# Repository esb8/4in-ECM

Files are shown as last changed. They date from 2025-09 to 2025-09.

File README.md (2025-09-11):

# Media
Use Export KiCad Images Workflow

---

<div align="center">
  <div>
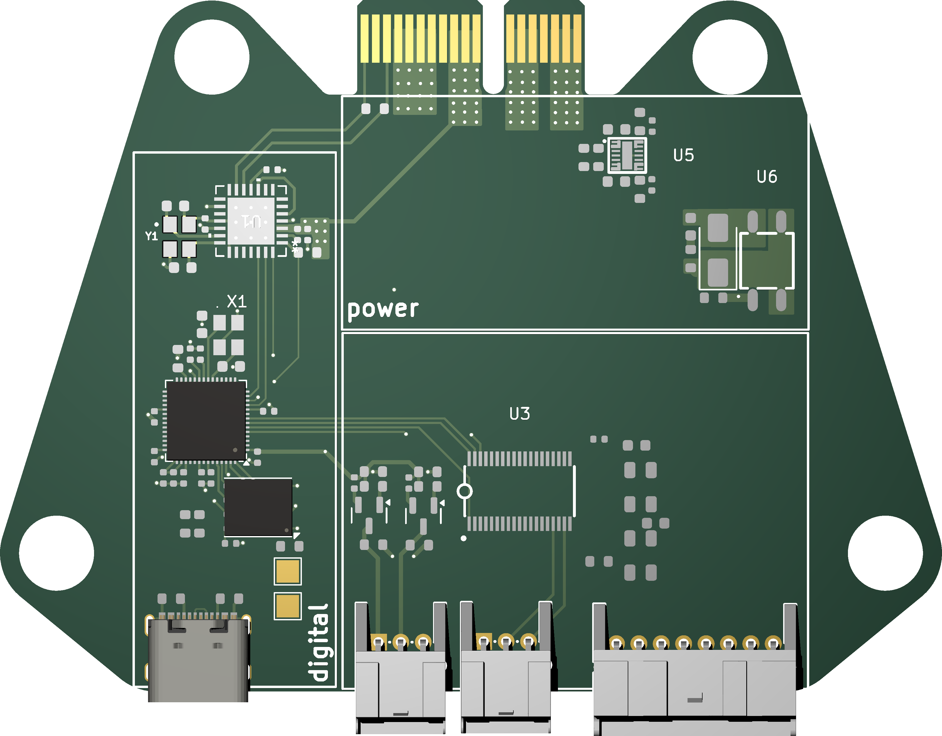
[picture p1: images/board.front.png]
    
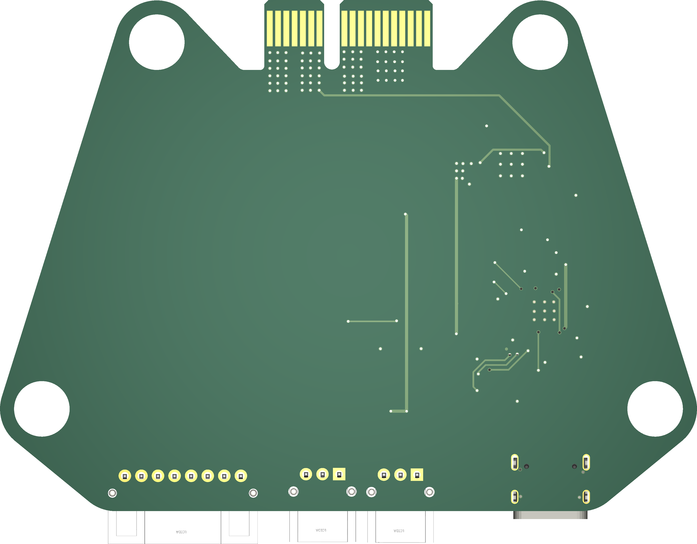
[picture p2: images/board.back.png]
    
    <p><em>3D Render</em></p>
  </div>
  <br>

  <div>
    Schematic<br>
    <p><em>Schematic</em></p>
  </div>
  <br>
  
  <div>
    Front
    Back<br>
    <em>Footprint</em>
  </div>
</div>

# Engine Control Module

## Overview  
The **Engine Control Module (ECM)** is a **control and data acquisition (DAQ) system** designed for liquid rocket engine testing. It integrates sensor measurement, actuation control, and data logging into a compact embedded system suitable for ground testing and development.  

The system is capable of:  
- Monitoring **up to 4 pressure transducers**  
- Reading multiple **thermocouples** for temperature measurement  
- Controlling **1 solenoid valve** (on/off flow control)  
- Driving **2 servo motors** (valve actuation or gimbal control)  
- Logging sensor data for analysis and verification  

---

## Features  
- **Data Acquisition**  
  - 4 analog channels for high-accuracy pressure transducers  
  - Integrated thermocouple interface for combustion chamber and feed line monitoring  
  - Real-time sampling and logging  

- **Actuation**  
  - Solenoid driver with high-side switching capability  
  - Dual servo motor outputs (PWM control)  
  - Configurable control logic for sequencing and automation  

- **System Control**  
  - Embedded microcontroller (e.g., STM32/Arduino/FPGA – specify)  
  - USB/UART interface for PC communication  
  - Safety interlocks and emergency shutdown support  

- **Software**  
  - Firmware for DAQ, control, and communications  
  - Logging utility for test data collection  
  - Configurable sampling rates and actuation sequences  

---

## Applications  
- Small-scale **liquid rocket engine testing**  
- **Valve and feed system automation**  
- **Sensor data acquisition** for propulsion research  
- **Ground support equipment** integration  

---

## Getting Started  
1. **Hardware Setup**  
   - Connect pressure transducers to the analog input ports (0–5 V or 0–10 V).  
   - Connect thermocouples to the thermocouple inputs.  
   - Wire solenoid to the high-side driver output.  
   - Connect servos to PWM headers.  

2. **Software Setup**  
   - Flash firmware using the provided source code.  
   - Install the DAQ/logging software on your PC.  
   - Configure serial port and sampling rate.  

3. **Operation**  
   - Power on the ECM.  
   - Verify sensor calibration.  
   - Execute control sequences via PC interface or onboard logic.  

---

## Safety Notes  
⚠️ This module is intended for **research and experimental use only**.  
- Always follow proper test stand safety procedures.  
- Use protective enclosures and remote operation where possible.  
- Ensure solenoid and servo actuation logic is validated before hot-fire testing.

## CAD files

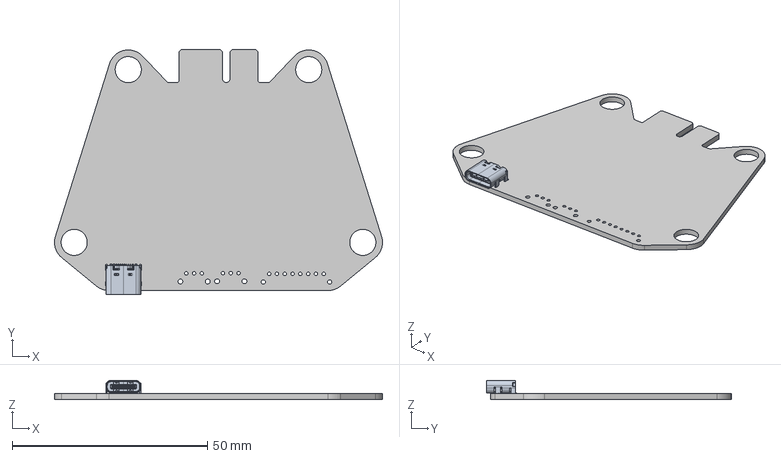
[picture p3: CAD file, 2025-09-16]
images/board.step
84.1 x 62.7 x 4.91 mm
USB_C_Receptacle_GCT_USB4105-xx-A_16P_TopMnt_Horizontal
ECM_PCB

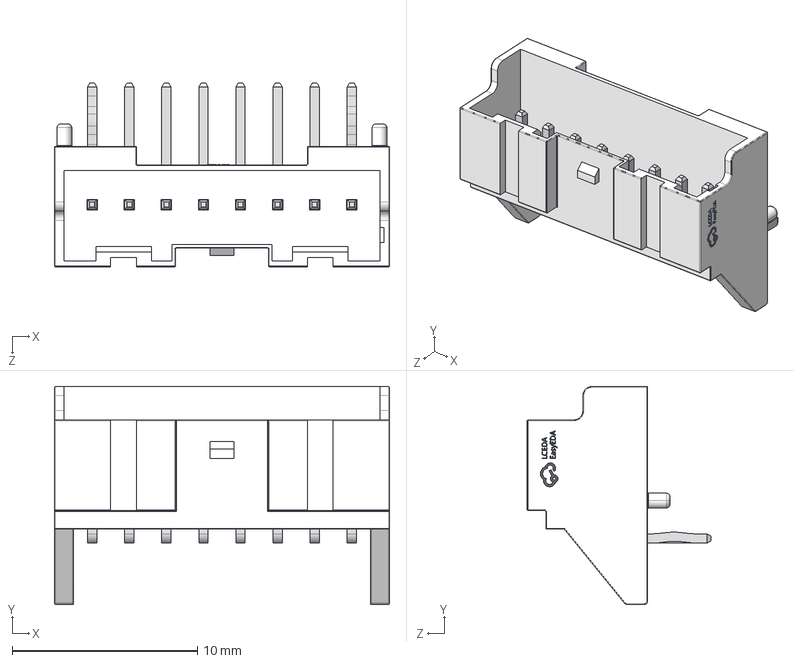
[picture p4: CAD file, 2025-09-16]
kicad/models/CONN-TH_S08B-PASK-2.step
18.1 x 11.8 x 9.90 mm

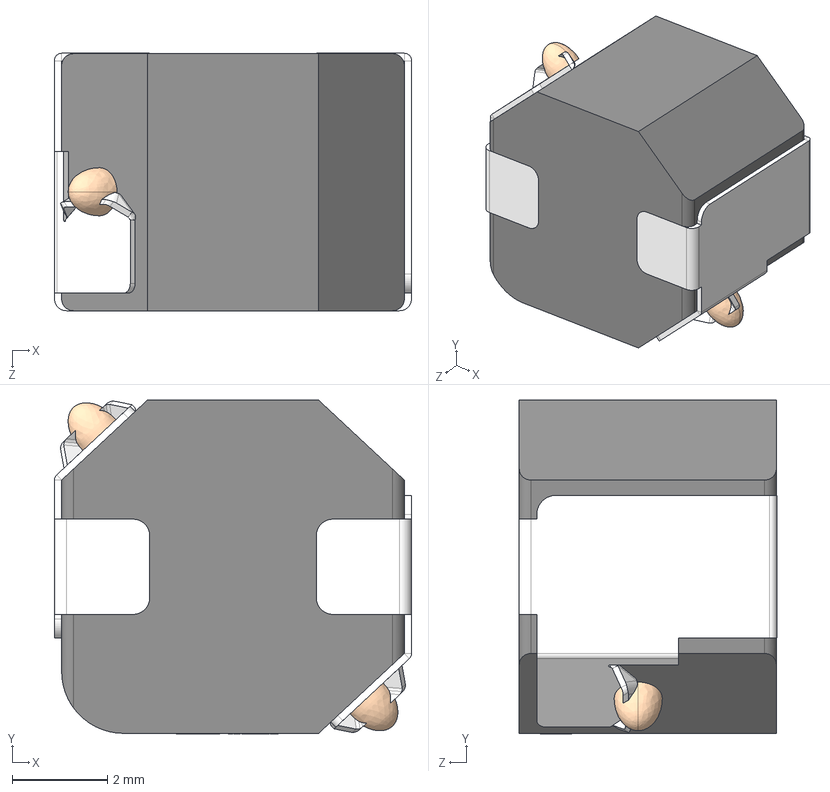
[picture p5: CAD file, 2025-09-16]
kicad/models/IND-SMD_L7.5-W7.0_SPM7054VT-330M-D.step
7.50 x 7.01 x 5.41 mm

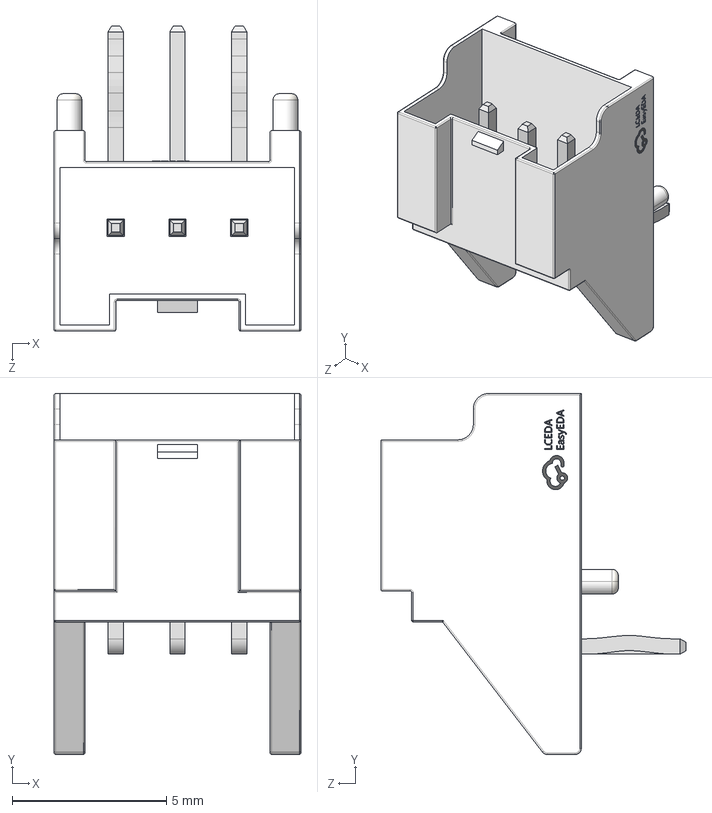
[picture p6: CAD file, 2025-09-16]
kicad/models/CONN-TH_S03B-PASK-2-LF-SN.step
8.00 x 11.7 x 9.90 mm

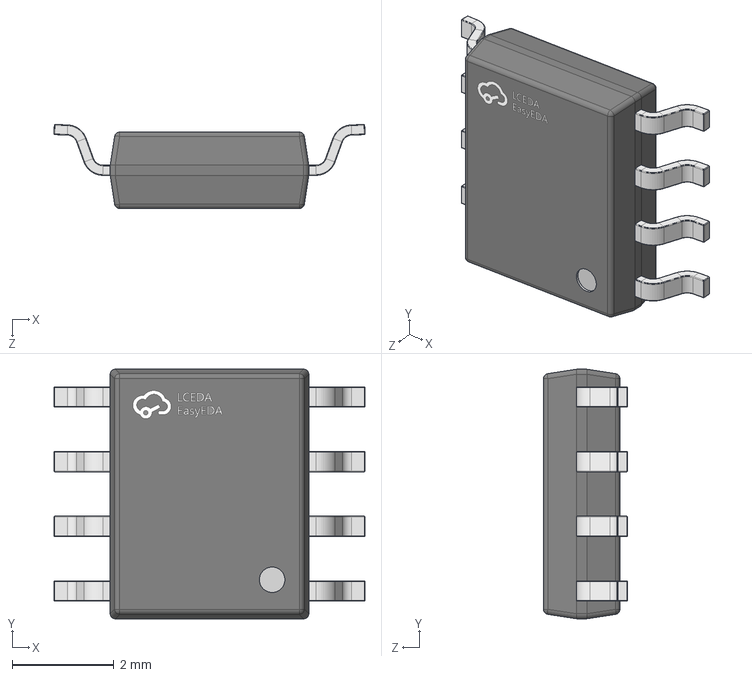
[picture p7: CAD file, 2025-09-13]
kicad/models/SO-8_L4.9-W3.9-H1.5-LS5.9-P1.27.step
6.11 x 4.90 x 1.65 mm

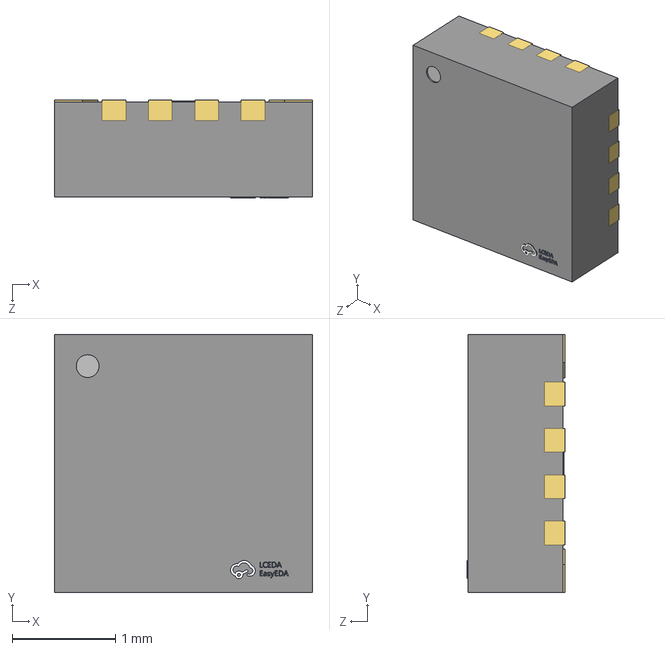
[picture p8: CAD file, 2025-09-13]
kicad/models/QFN-16_L2.5-W2.5-P0.45-TL-EP0.6.step
2.50 x 2.50 x 0.95 mm

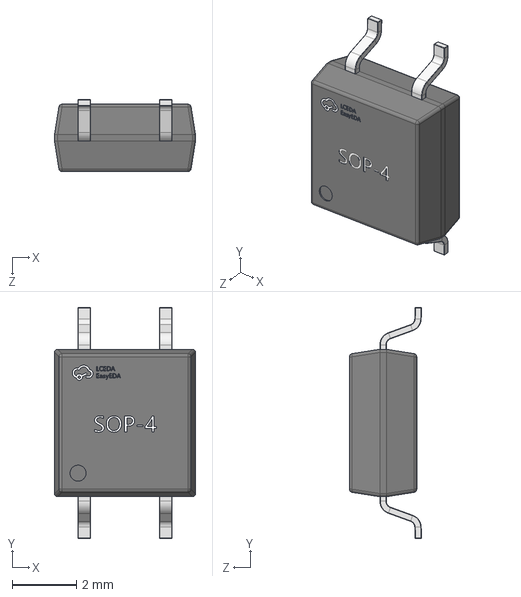
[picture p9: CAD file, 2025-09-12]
kicad/models/SOP-4_L4.4-W4.6-H2.1-LS7.0-P2.54.step
4.40 x 7.21 x 2.25 mm

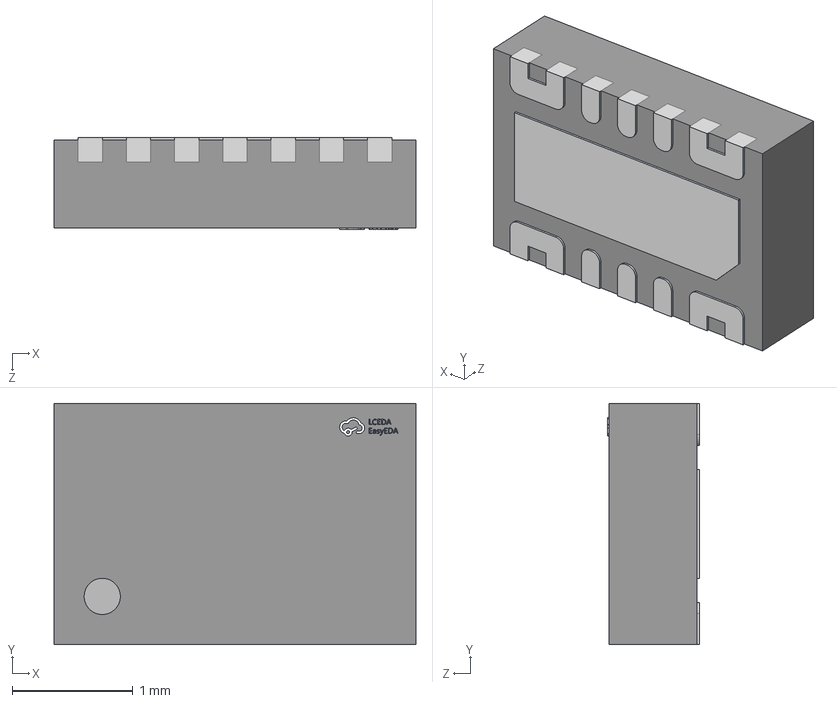
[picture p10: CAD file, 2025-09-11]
kicad/models/WSON-14_L3.0-W2.0-P0.40-BL-EP-1.step
3.00 x 2.00 x 0.76 mm

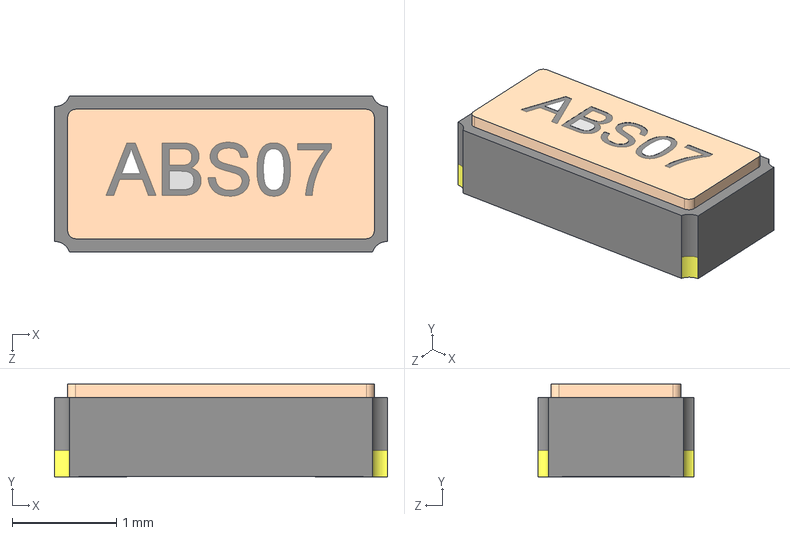
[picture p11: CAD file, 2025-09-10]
kicad/models/ABS07-32.768KHZ-T.step
3.20 x 0.889 x 1.50 mm

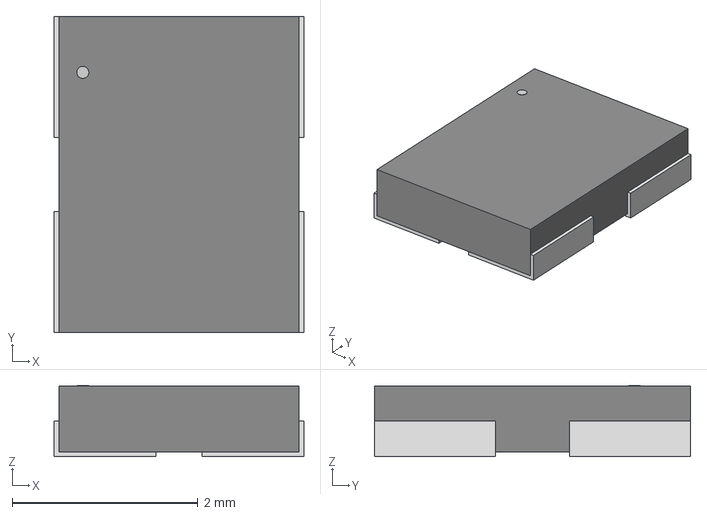
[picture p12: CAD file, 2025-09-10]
kicad/models/ABM8-272-T3_ABR.step
2.69 x 3.40 x 0.765 mm

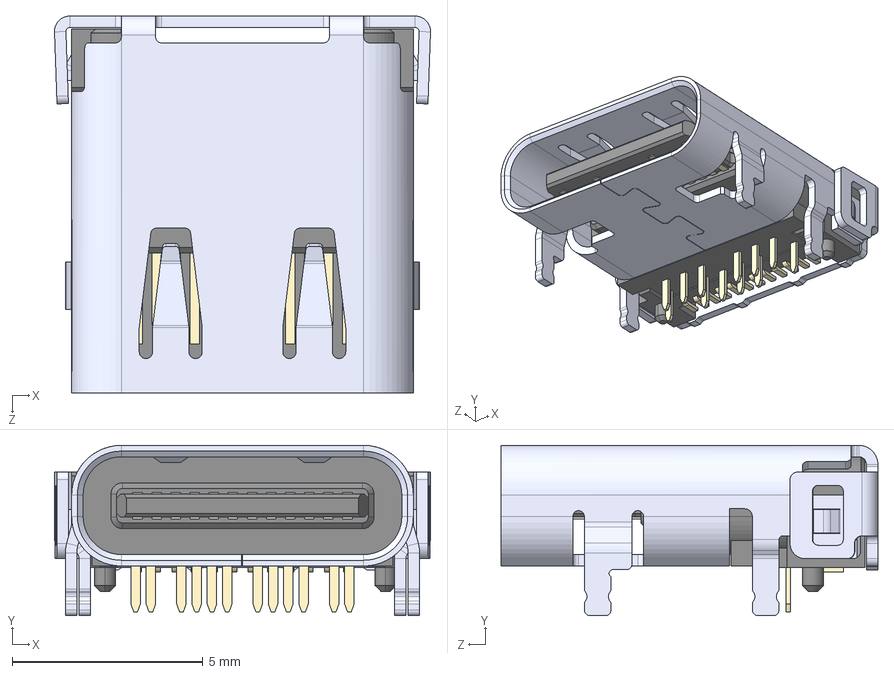
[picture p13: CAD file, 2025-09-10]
kicad/models/TYPE-C-31-M-04.step
9.85 x 4.46 x 9.87 mm

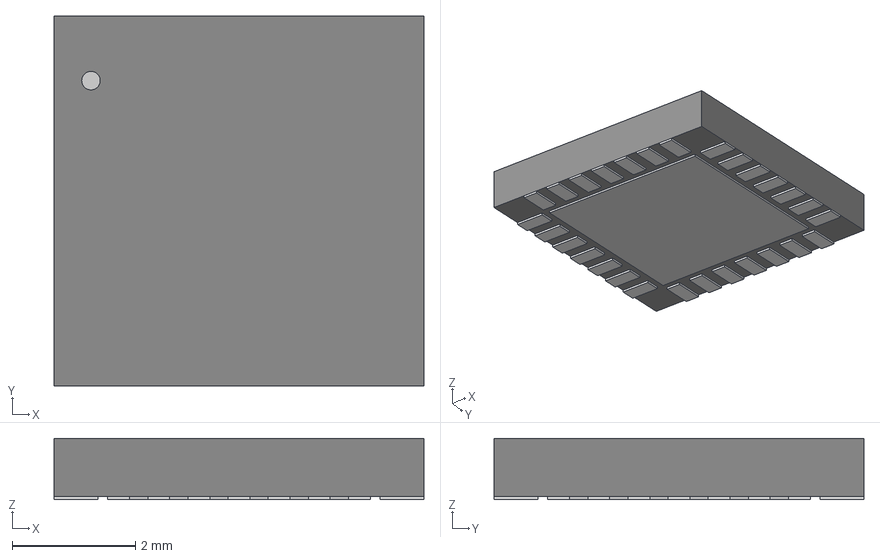
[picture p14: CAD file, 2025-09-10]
kicad/models/QFN28_6X6MC_MCH.step
5.99 x 5.99 x 0.993 mm

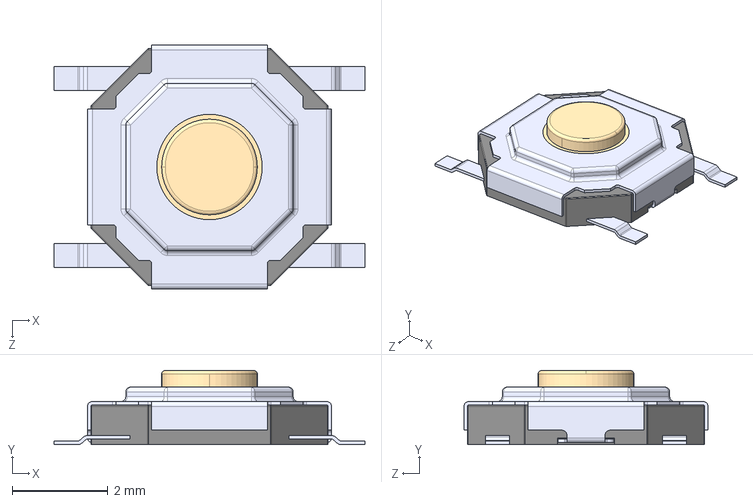
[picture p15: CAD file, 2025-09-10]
kicad/models/TS-1187A-B-A-B.step
6.50 x 1.55 x 5.10 mm

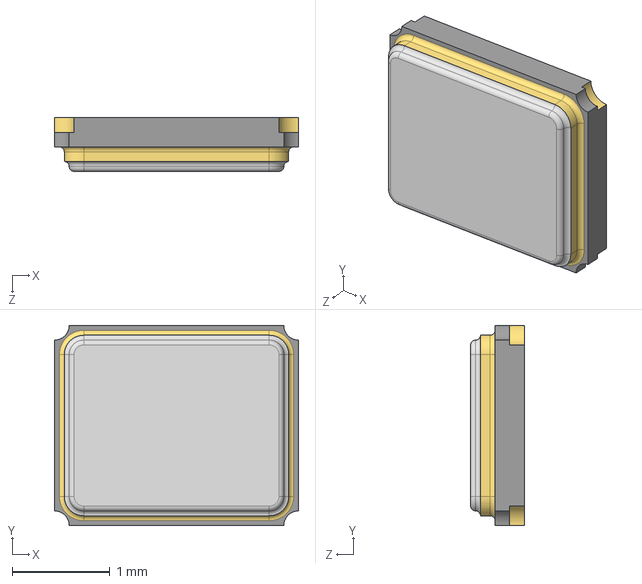
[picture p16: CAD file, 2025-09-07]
kicad/models/CRYSTAL-SMD_4P-L2.5-W2.0-BL-A.step
2.50 x 2.05 x 0.551 mm

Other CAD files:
kicad/models/X322516MLB4SI.step

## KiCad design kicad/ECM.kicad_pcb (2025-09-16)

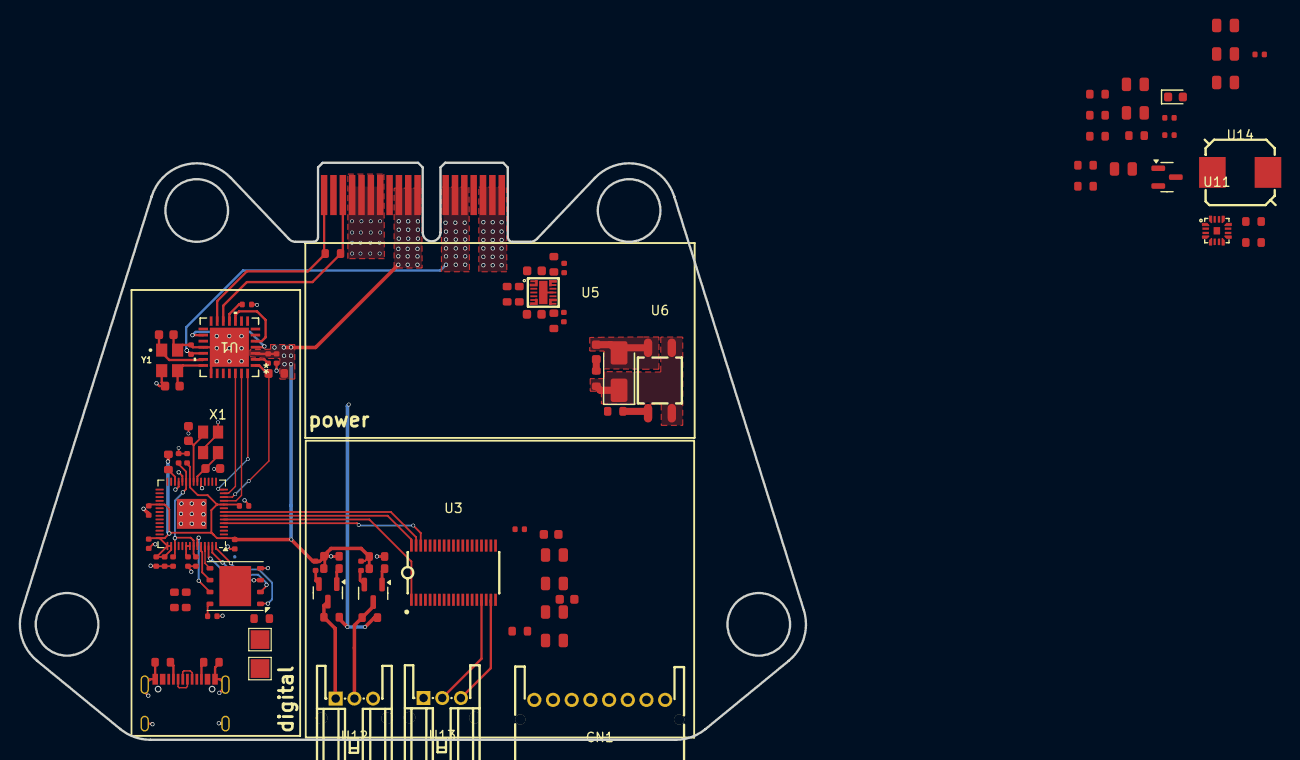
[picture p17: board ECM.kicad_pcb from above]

Board: 4 copper layers, 84.1 x 61.7 mm, 92 parts (1 on the bottom side), 66 nets.

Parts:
C1, C2, C4, C5, C6, C7, C8, C9, C10, C14, C15, C16, C17, C29, C30, C37: 100nF; C_0402
C3, C11, C23: 1uF; C_0402
C12, C13: 15pF; C_0603
C18, C21, C24, C28: 1uF; C_0603
C19, C20: 22pF; C_0603
C22, C25, C26, C27, C38, C39, C40, C41, C42: 10uF; C_0805
C31: 22nF; C_0603
C36: 2.2uF; C_0805
C43: 220pF; C_0402
CN1: S08B-PASK-2(LF)(SN); CONN-TH_S08B-PASK-2
D1: SS210; D_SMA
D2: White; D_0603
J1: Bus_PCI_Express_x1; BUS_PCIexpress_x1
J6: USB_C_Receptacle_USB2.0_16P; USB_C_Receptacle_Palconn_UTC16-G
Q1, Q2, Q3: AO3400A; Q_SOT-23
R1, R4, R37: 1kΩ; R_0603
R2, R3, R8: 27Ω; R_0603
R5, R6, R10, R11, R12, R13, R16, R17, R19, R20, R32, R34: 5.1kΩ; R_0603
R7: 300Ω; R_0603
R9, R15, R18, R33, R35: 120Ω; R_0603
R14, R21: 10Ω; R_0603
R22, R23, R24, R29: 10kΩ; R_0402
R30, R36: 160kΩ; R_0603
R31: 22kΩ; R_0603
U1: MCP25625T-E/ML; QFN28_6X6MC_MCH
U2: RP2040; QFN-56-1EP_7x7mm_P0.4mm_EP3.2x3.2mm
U3: ADS8688IDBTR; TSSOP-38_L9.7-W4.4-P0.50-LS6.4-BL
U4: W25Q128JVP; WSON-8-1EP_6x5mm_P1.27mm_EP3.4x4.3mm
U5: TPS22976DPUR; WSON-14_L3.0-W2.0-P0.40-BL-EP-1
U6: GAQY252G3S; SOP-4_L4.3-W4.4-P2.54-LS7.0-BL
U11: SY8388ARHC; QFN-16_L2.5-W2.5-P0.45-TL-EP0.6
U12, U13: S03B-PASK-2; CONN-TH_S03B-PASK-2-LF-SN
U14: SPM7054VT-4R7M-D; IND-SMD_L7.5-W7.0_SPM7054VT-330M-D
X1: ABM8-272-T3; ABM8-272-T3_ABR
Y1: X322516MLB4SI; OSC_X322516MLB4SI

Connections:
+1V1: C1.1, C2.1, C3.1, U2.23 (DVDD), U2.45 (VREG_VOUT), U2.50 (DVDD)
+3.3V: C4.1, C5.1, C6.1, C7.1, C8.1, C9.1, C10.1, C11.1, C14.2, C15.2, C17.2, C25.1, J1.A9 (+3.3V), J1.A10 (+3.3V), J1.A11 (~PERST), J1.B9 (JTAG1), J1.B10 (3.3Vaux), J1.B11 (~WAKE), R4.2, R7.1, R10.1, R11.1, R15.1, R16.2, R17.2, R18.1, R22.2, R23.2, R24.2, U1.3 (VDD), U1.11 (VIO), U2.1 (IOVDD), U2.10 (IOVDD), U2.22 (IOVDD), U2.33 (IOVDD), U2.42 (IOVDD), U2.43 (ADC_AVDD), U2.44 (VREG_IN), U2.48 (USB_VDD), U2.49 (IOVDD), U3.34 (DVDD), U4.8 (VCC)
+5V: C16.1, C23.2, C24.1, J1.A12 (GND), J1.A13 (REFCLK+), J1.A14 (REFCLK-), J1.B12 (RSVD), J1.B13 (GND), J1.B14 (PETp0), U1.19 (VDDA), U3.9 (AVDD), U3.30 (AVDD)
+5V_Servo: C21.1, C28.1, C40.1, C41.1, C42.1, C43.1, R19.2, R20.2, R30.1, R33.1, R34.2, U5.1 (VIN1), U5.2 (VIN1), U5.4 (VBIAS), U5.6 (VIN2), U5.7 (VIN2), U14.1
+24V: C31.1, C38.2, C39.1, D1.2, R36.2, U6.4, U11.2 (IN), U11.3 (IN), U11.4 (IN), U12.3
+BAT: J1.A16 (PERp0), J1.A17 (PERn0), J1.A18 (GND), J1.B16 (GND), J1.B17 (~PRSNT2), J1.B18 (GND)
/3.3V_PWM1: Q1.2 (S), R22.1
/3.3V_PWM2: Q2.2 (S), R23.1
/5V_PWM1: Q1.3 (D), R20.1, U12.2
/5V_PWM2: Q2.3 (D), R19.1, U12.1
/AIN_0IN: U3.16 (AIN_0P), U13.2
/AIN_1IN: U3.18 (AIN_1P), U13.3
/CANH: J1.A1 (~PRSNT1), R9.2, U1.13 (CANH)
/CANL: J1.A3 (+12V), R9.1, U1.12 (CANL)
/CAN_OSC1: C19.1, U1.21 (OSC1), Y1.3
/CAN_OSC2: C20.1, U1.20 (OSC2), Y1.1
/FB: R30.2, R31.1, R37.2, U11.11 (FB)
/LX: C37.1, U11.5 (LX), U11.15 (LX), U11.16 (LX), U14.2
/MODE: R32.2, U11.8 (MODE)
/QSPI_SCLK: U2.52 (QSPI_SCLK), U4.6 (CLK)
/QSPI_SD0: U2.53 (QSPI_SD0), U4.5 (DI(IO0))
/QSPI_SD1: U2.55 (QSPI_SD1), U4.2 (DO(IO1))
/QSPI_SD2: U2.54 (QSPI_SD2), U4.3 (IO2)
/QSPI_SD3: U2.51 (QSPI_SD3), U4.7 (IO3)
/QSPI_SS: R1.2, U2.56 (QSPI_SS), U4.1 (~CS)
/REFCAP: C18.1, C22.1, C27.2, U3.7 (REFCAP)
/REFGND: C18.2, C22.2, C27.1, U3.6 (REFGND)
/REFIO: C26.2, U3.5 (REFIO)
/RXCAN: U1.5 (RXCAN), U1.10 (RXD)
/SERVO_ON1: R13.2, U5.3 (ON1)
/SERVO_ON2: R12.2, U5.5 (ON2)
/SERVO_PWR1: C29.1, CN1.7, R14.1, U5.13 (VOUT1), U5.14 (VOUT1)
/SERVO_PWR2: C30.1, CN1.8, R21.1, U5.8 (VOUT2), U5.9 (VOUT2)
/SPI0_CS0: R10.2, U2.3 (GPIO1), U2.7 (GPIO5), U2.28 (GPIO17), U2.32 (GPIO21), U3.38 (~CS)
/SPI0_MISO: U2.5 (GPIO3), U2.9 (GPIO7), U2.30 (GPIO19), U2.35 (GPIO23), U3.36 (SDO)
/SPI0_MOSI: U2.2 (GPIO0), U2.6 (GPIO4), U2.27 (GPIO16), U2.31 (GPIO20), U3.1 (SDI)
/SPI0_SCK: U2.4 (GPIO2), U2.8 (GPIO6), U2.29 (GPIO18), U2.34 (GPIO22), U3.37 (SCLK)
/SPI1_CS0: R11.2, U1.1 (*CS), U2.12 (GPIO9), U2.16 (GPIO13), U2.37 (GPIO25)
/SPI1_MISO: U1.28 (SO), U2.14 (GPIO11), U2.18 (GPIO15)
/SPI1_MOSI: U1.27 (SI), U2.11 (GPIO8), U2.15 (GPIO12), U2.36 (GPIO24)
/SPI1_SCK: U1.26 (SCK), U2.13 (GPIO10), U2.17 (GPIO14)
/TXCAN: U1.4 (TXCAN), U1.16 (TXD)
/USB_DM: J6.A7 (D-), J6.B7 (D-)
/USB_DN: J6.A6 (D+), J6.B6 (D+), R3.2
/XIN: C13.1, U2.20 (XIN), X1.3
/XOUT: C12.1, U2.21 (XOUT), X1.1
GND: C1.2, C2.2, C3.2, C4.2, C5.2, C6.2, C7.2, C8.2, C9.2, C10.2, C11.2, C12.2, C13.2, C14.1, C15.1, C16.2, C17.1, C19.2, C20.2, C21.2, C23.1, C24.2, C25.2, C26.1, C28.2, C29.2, C30.2, C36.2, C38.1, C39.2, C40.2, C41.2, C42.2, CN1.1, CN1.2, CN1.3, D1.1, D2.1, J1.A4 (GND), J1.A5 (JTAG2), J1.A6 (JTAG3), J1.A7 (JTAG4), J1.B1 (+12V), J1.B2 (+12V), J1.B3 (+12V), J1.B4 (GND), J1.B5 (SMCLK), J1.B6 (SMDAT), J1.B7 (GND), J6.A1 (GND), J6.A12 (GND), J6.B1 (GND), J6.B12 (GND), J6.S1 (SHIELD), R5.2, R6.2, R8.2, R12.1, R13.1, R14.2, R16.1, R17.1, R21.2, R29.1, R31.2, U1.18 (VSS), U1.22 (GND), U1.29 (EPAD), U2.19 (TESTEN), U2.57 (GND), U3.3 (DAISY), U3.4 (~REFSEL), U3.8 (AGND), U3.28 (AGND), U3.29 (AGND), U3.31 (AGND), U3.32 (AGND), U3.33 (DGND), U4.4 (GND), U5.11 (GND), U5.15 (EP), U6.2, U6.3, U11.6 (GND), U11.14 (GND), U11.17 (GND), U13.1, X1.2, X1.4, Y1.2, Y1.4
unnamed: C31.2, R8.1
unnamed: C43.2, R37.1
unnamed: J6.A5 (CC1), R5.1
unnamed: J6.B5 (CC2), R6.1
unnamed: Q1.1 (G), R15.2
unnamed: Q2.1 (G), R18.2
unnamed: Q3.3 (D), R35.2
unnamed: Q3.1 (G), R34.1, U11.7 (PG)
unnamed: D2.2, Q3.2 (S)
unnamed: R7.2, U6.1
unnamed: R33.2, R35.1
unnamed: R4.1, U2.26 (RUN)
unnamed: R24.1, U1.2 (*RESET)
unnamed: R3.1, U2.46 (USB_DM)
unnamed: R2.2, U2.47 (USB_DP)
unnamed: C37.2, U11.1 (BS)
unnamed: R36.1, U11.9 (EN)
unnamed: R29.2, U11.10 (ILMT)
unnamed: C36.1, U11.13 (VCC)

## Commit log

2025-09-07 First Commit: Added MCU, DAQ IC, and a few connectors
    [ECM.kicad_pcb, ECM.kicad_sch]
2025-09-07 Cleaned out old ECM pro file
    [ECM.kicad_pcb, ECM.kicad_sch]
2025-09-10 followed MACH Template
    [ABM8-272-T3_ABR.step, ABS07-32.768KHZ-T.step, CRYSTAL-SMD_4P-L2.5-W2.0-BL-A.step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]
2025-09-11 Schematic Capture of RP2040, CAN Network, USB-C, Memory, DAQ, Servo Drivers and PWM Level Shifter.
    [ECM.kicad_pcb, ECM.kicad_sch, WSON-14_L3.0-W2.0-P0.40-BL-EP-1.step]
2025-09-11 Update images
    [board.step]
2025-09-12 Added control circuitry for Servos, PWM Level Shifting, and Solenoid Driving, Next Steps: Thermocouples and CJC
    [ECM.kicad_sch, SOP-4_L4.4-W4.6-H2.1-LS7.0-P2.54.step]
2025-09-13 Added thermocouple ICs and dc/dc circuitry for servo power
    [ECM.kicad_pcb, ECM.kicad_sch, SO-8_L4.9-W3.9-H1.5-LS5.9-P1.27.step]
2025-09-14 Preliminary PCB Layout on most ICs, carved out analog, power and digital regions.
    [ECM.kicad_pcb, ECM.kicad_sch]
2025-09-14 More progress on layout
    [ECM.kicad_pcb, ECM.kicad_sch]
2025-09-16 feat: added latching connectors
    [CONN-TH_S03B-PASK-2-LF-SN.step, CONN-TH_S08B-PASK-2.step, ECM.kicad_pcb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]
